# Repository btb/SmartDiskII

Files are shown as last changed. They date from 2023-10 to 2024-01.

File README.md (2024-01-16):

# SmartDiskII

The SmartDiskII is basically an Apple "Liron" disk controller with the IWM chip
replaced by the discrete components from the Disk II controller, which
the IWM was originally based on, and using firmware (i.e. SoftSP) which
has been appropriately modified to use those components instead of the IWM.

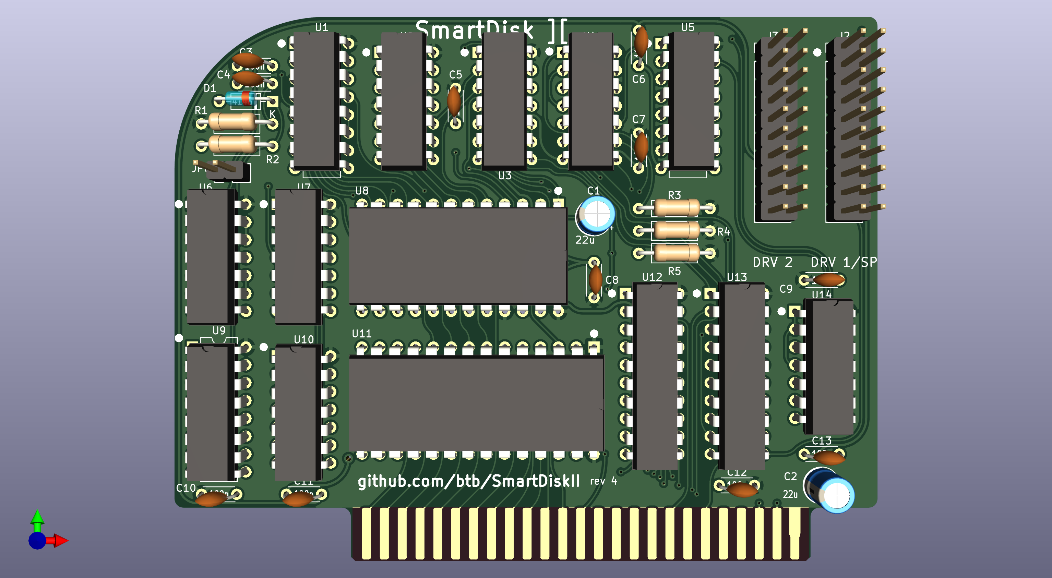
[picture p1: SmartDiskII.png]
image info


[Interactive BOM](https://btb.github.io/SmartDiskII/bom/SmartDiskII.html)

## SmartPort Operation

Because the SoftSP firmware (as of v6) is slot-dependent, a different copy is
required for each slot the card may be used in. The slot 1 version is in the 1xxx
region of the EPROM, slot 2 version is at 2xxx, etc.
A set of latches (U9) is used to automatically select the appropriate region
depending on which slot the SmartDiskII is placed in.

## Disk II Operation (experimental)

The card is designed to also work as a regular Disk II controller, though 
results can be inconsistent depending on the components used. Failures of 
this system can lead to corrupted floppy disks.

For this reason it is recommended to use true TTL ICs for all of the logic 
chips. In addition, for the chip at U5, Apple's original Disk II 
controller design called for a 9334 rather than a 74LS259. Indeed, using a 
9334 does appear to make the circuit more tolerant of these issues.  

5.25 Floppy operation works by having the Disk II boot rom in the 0xxx
region of the EPROM, and therefore active while U9 is held in
reset. Plugging a floppy drive into the DRV1 connector should automatically
activate the correct firmware because of the presence of +5V on pin 12, but
because some devices do not have that pin connected,
you can also close jumper JP8 to force the card into Disk II boot mode.

## Configuration

U8 is the standard [16-sector Disk II state machine data, P6](firmware/341-0128_P6A.bin), on a 2716-compatible EPROM.

U11 is a special combination of the Disk II boot ROM and the SoftSP firmware, [SmartDiskII.bin](firmware/SmartDiskII.bin).

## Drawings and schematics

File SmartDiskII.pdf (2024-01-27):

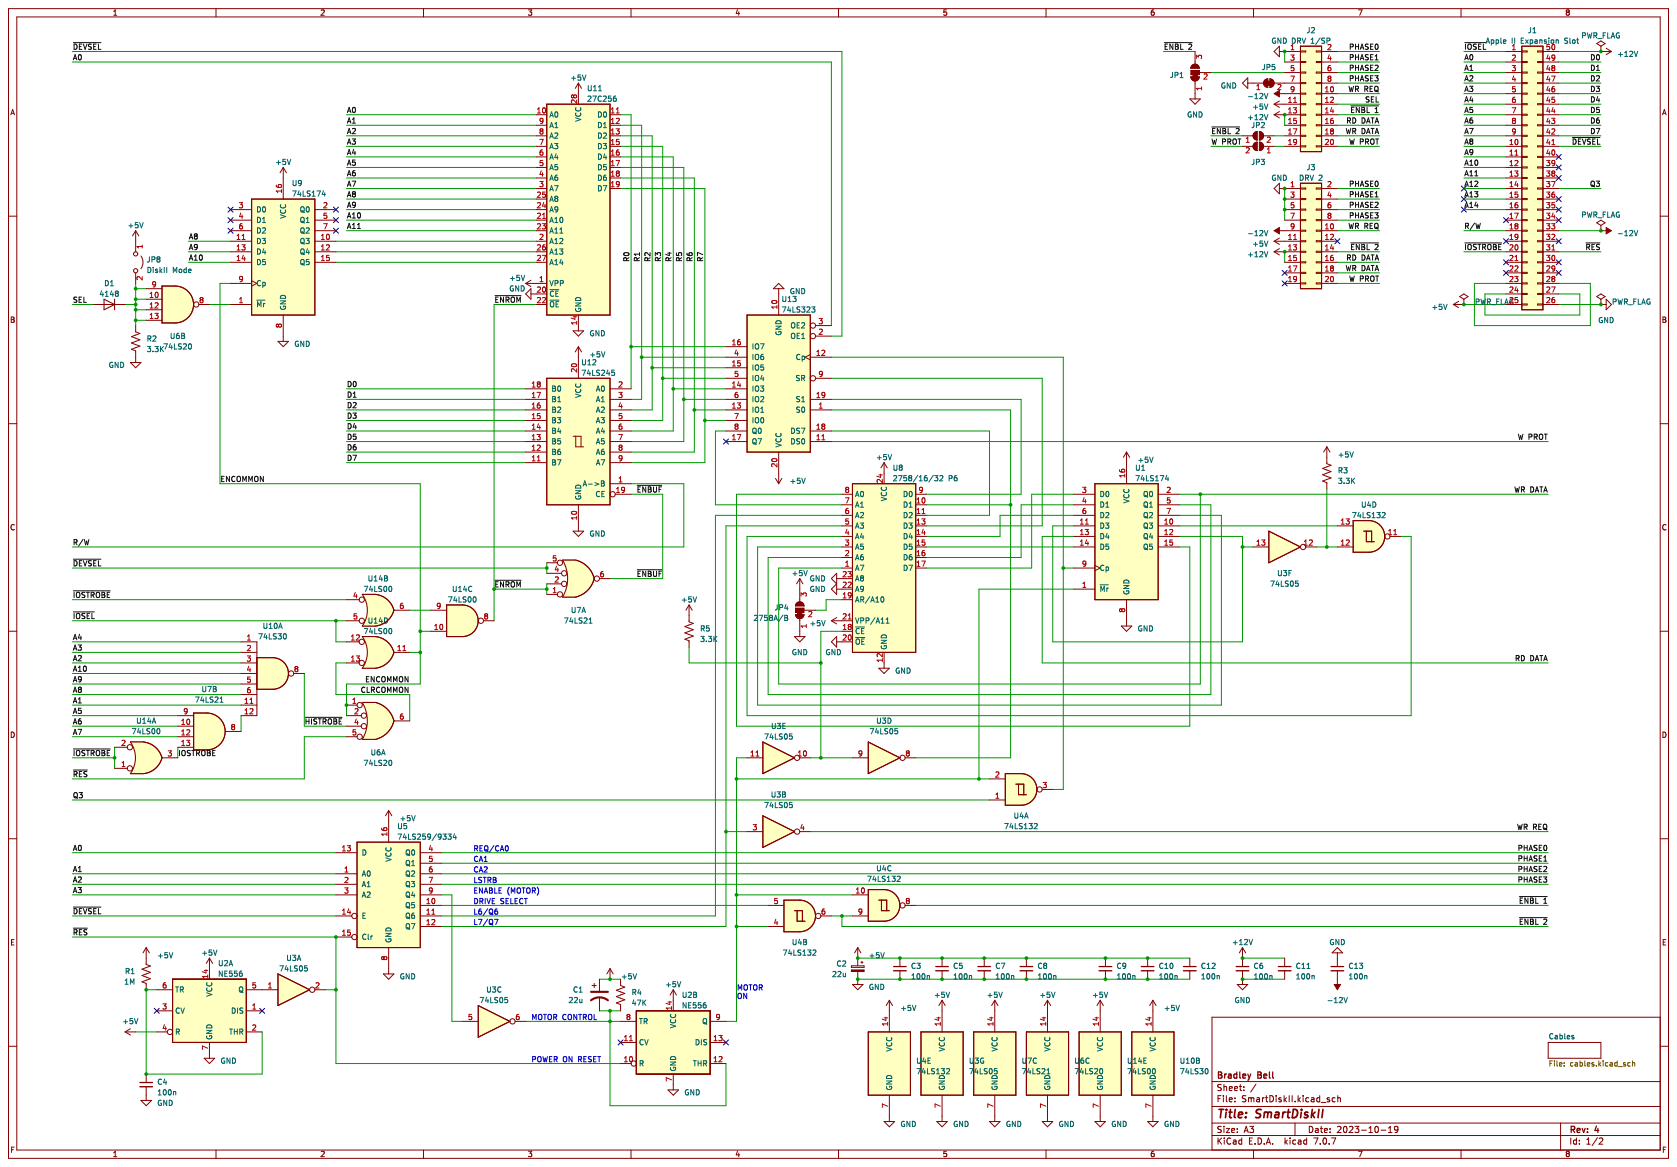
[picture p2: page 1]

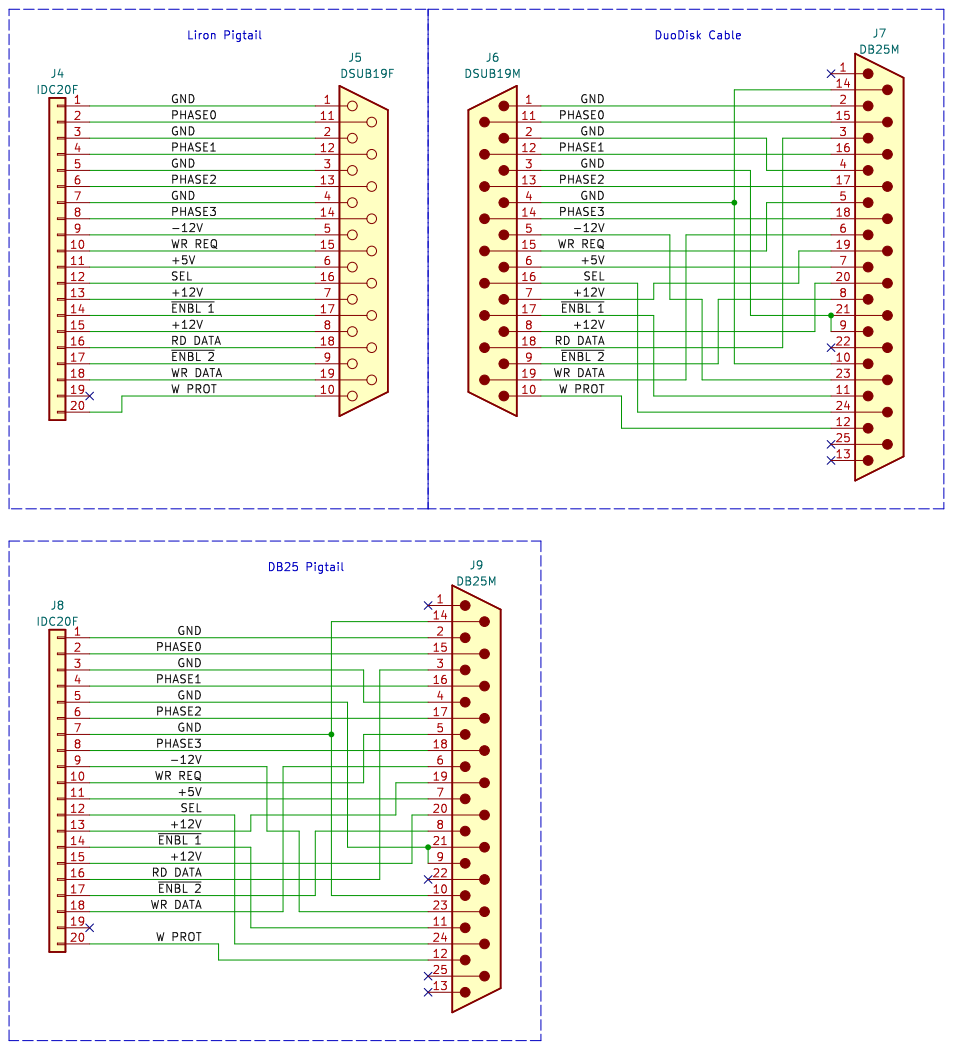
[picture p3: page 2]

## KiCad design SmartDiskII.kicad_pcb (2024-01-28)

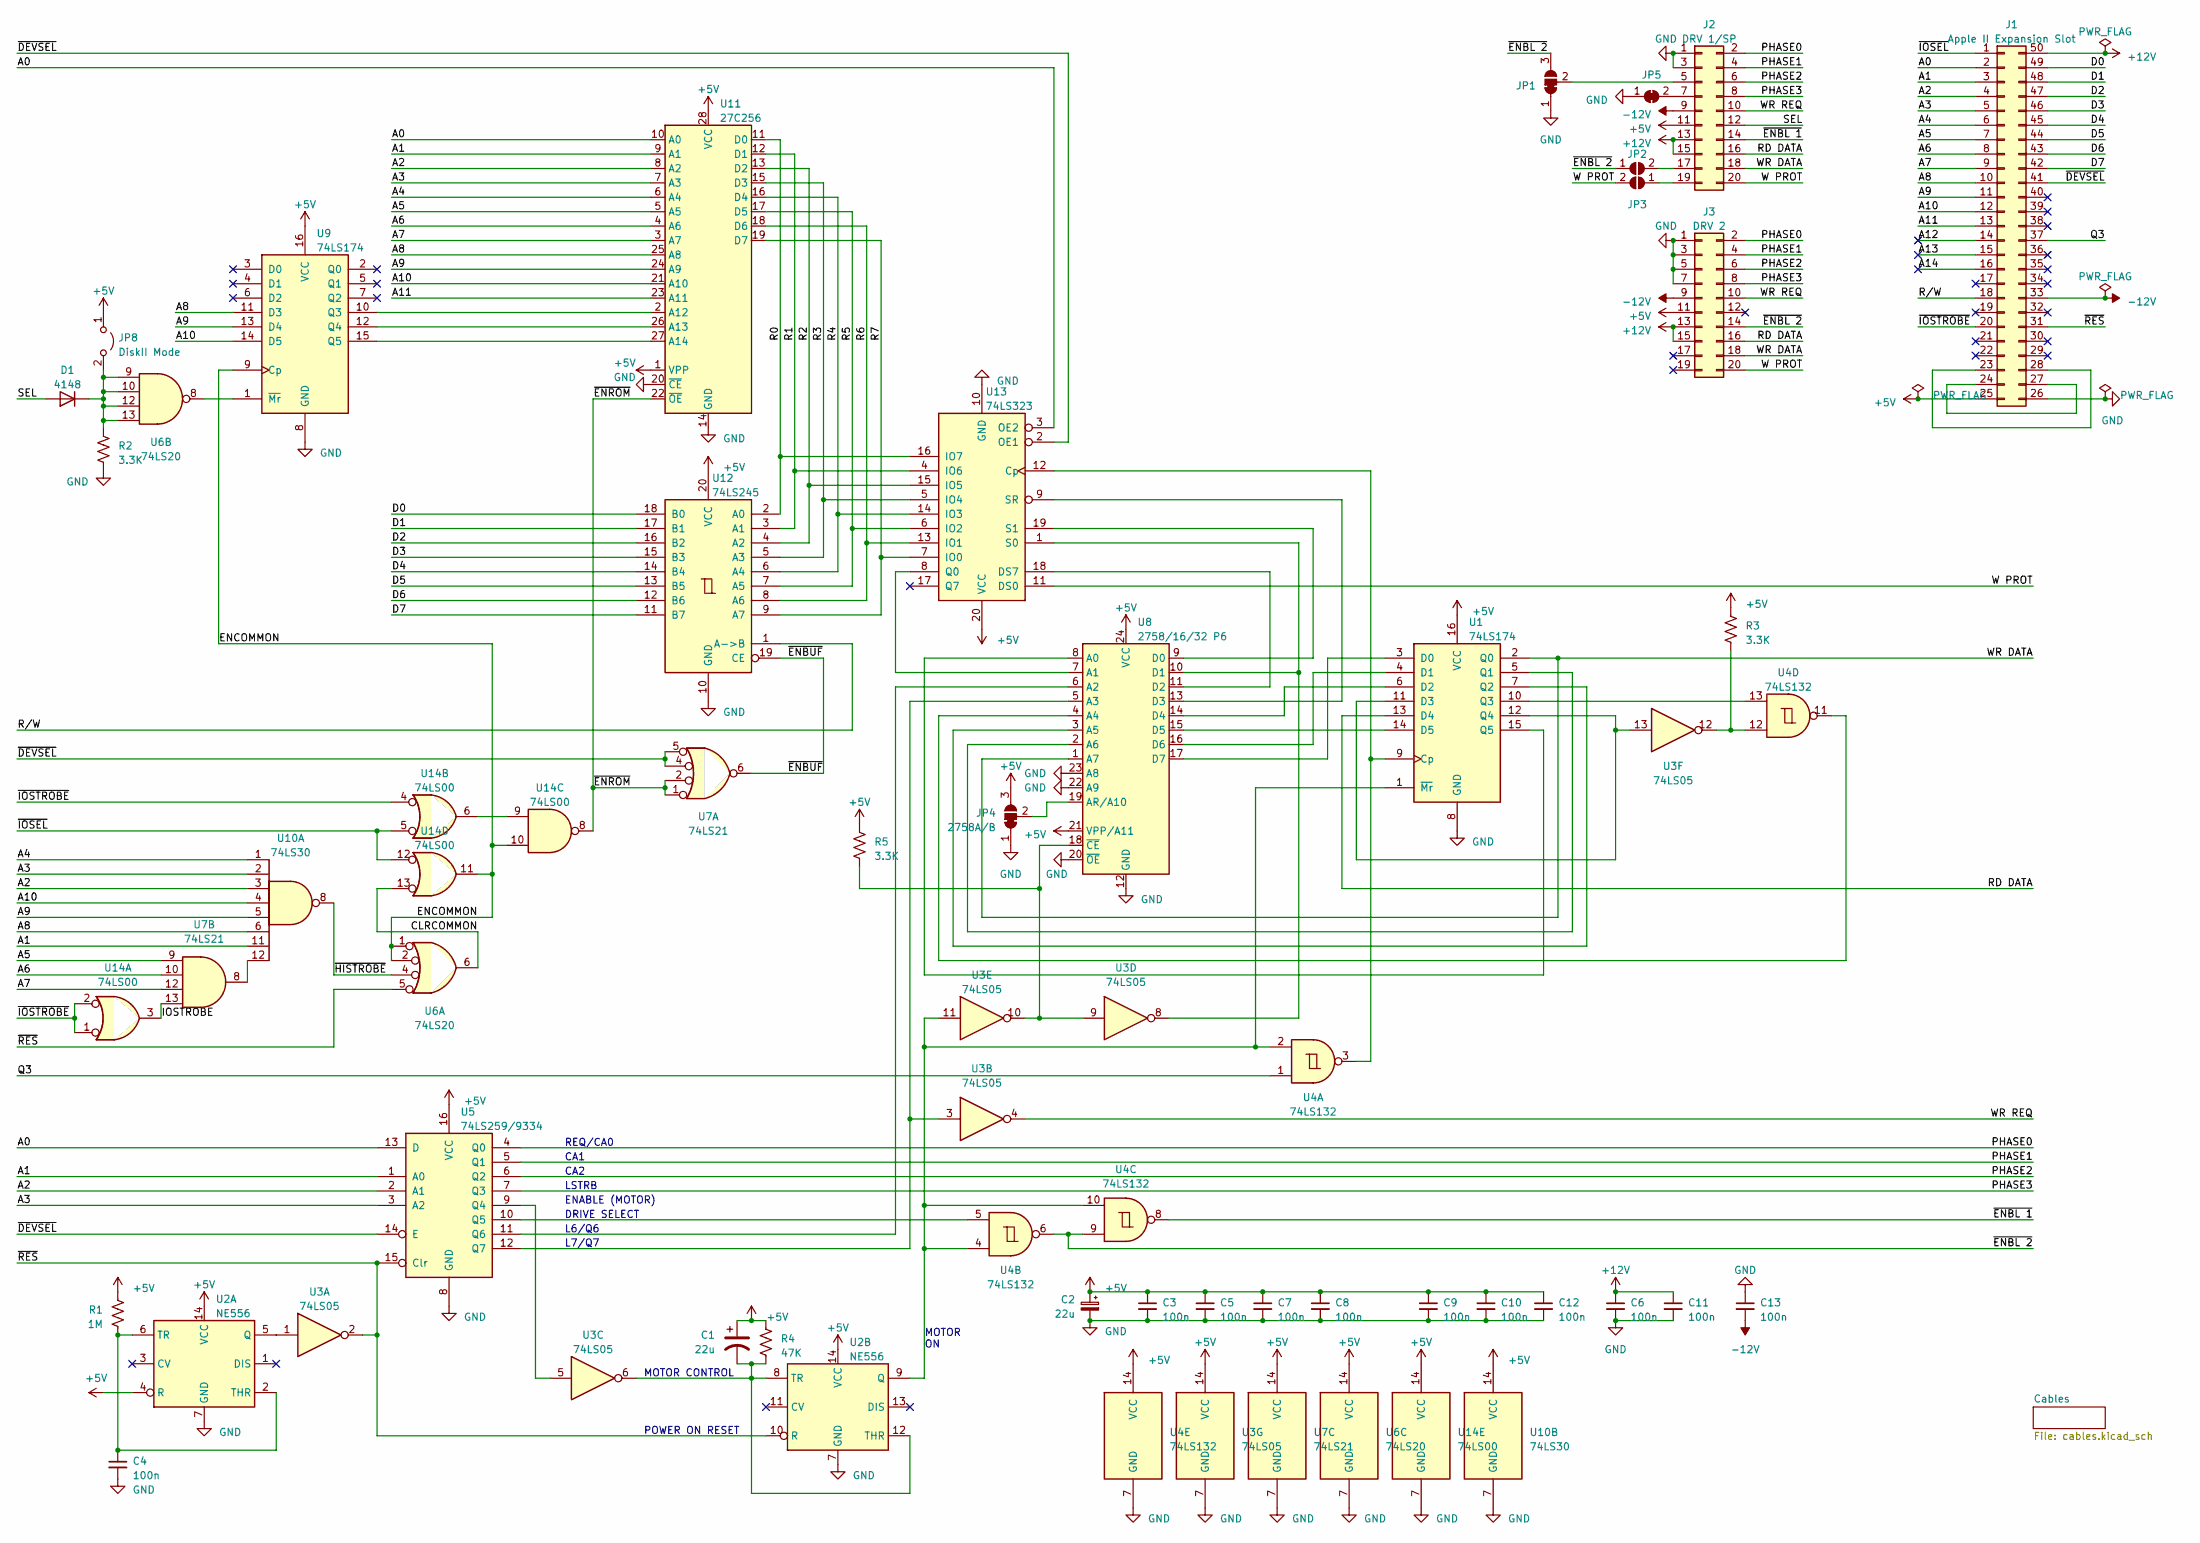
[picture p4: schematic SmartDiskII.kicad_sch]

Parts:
C1, C2: 22u; CP_Radial_D5.0mm_P2.50mm
C3, C4, C5, C6, C7, C8, C9, C10, C11, C12, C13: 100n; C_Disc_D4.3mm_W1.9mm_P5.00mm
D1: 4148; D_DO-35_SOD27_P7.62mm_Horizontal
J1: Apple II Expansion Slot; Apple II Expansion Edge Connector
J2: DRV 1/SP; PinHeader_2x10_P2.54mm_Vertical_Shrouded
J3: DRV 2; PinHeader_2x10_P2.54mm_Vertical_Shrouded
JP1: SolderJumper-3_P1.3mm_Bridged12_RoundedPad1.0x1.5mm_NumberL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
JP2, JP3: SolderJumper-2_P1.3mm_Open_RoundedPad1.0x1.5mm
JP4: 2758A/B; SolderJumper-3_P1.3mm_Bridged12_RoundedPad1.0x1.5mm_NumberL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
JP5: SolderJumper-2_P1.3mm_Bridged_RoundedPad1.0x1.5mm
JP8: DiskII Mode; PinHeader_1x02_P2.54mm_Vertical
R1: 1M; R_Axial_DIN0207_L6.3mm_D2.5mm_P10.16mm_Horizontal
R2, R3, R5: 3.3K; R_Axial_DIN0207_L6.3mm_D2.5mm_P10.16mm_Horizontal
R4: 47K; R_Axial_DIN0207_L6.3mm_D2.5mm_P10.16mm_Horizontal
U1, U9: 74LS174; DIP-16_W7.62mm
U2: NE556; DIP-14_W7.62mm
U3: 74LS05; DIP-14_W7.62mm
U4: 74LS132; DIP-14_W7.62mm
U5: 74LS259/9334; DIP-16_W7.62mm
U6: 74LS20; DIP-14_W7.62mm
U7: 74LS21; DIP-14_W7.62mm
U8: 2758/16/32 P6; DIP-24_W15.24mm
U10: 74LS30; DIP-14_W7.62mm
U11: 27C256; DIP-28_W15.24mm
U12: 74LS245; DIP-20_W7.62mm
U13: 74LS323; DIP-20_W7.62mm
U14: 74LS00; DIP-14_W7.62mm

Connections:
+5V: C1.1, C2.1, C3.1, C5.1, C7.1, C8.1, C9.1, C10.1, C12.1, J1.25, J2.11, J3.11, JP4.3 (B), JP8.1 (A), R1.1, R3.1, R4.2, R5.1, U1.16 (VCC), U2.4 (R), U2.14 (VCC), U3.14 (VCC), U4.14 (VCC), U5.16 (VCC), U6.14 (VCC), U7.14 (VCC), U8.21 (VPP/A11), U8.24 (VCC), U9.16 (VCC), U10.14 (VCC), U11.1 (VPP), U11.28 (VCC), U12.20 (VCC), U13.20 (VCC), U14.14 (VCC)
+12V: C6.1, C11.1, J1.50, J2.13, J2.15, J3.13, J3.15
-12V: C13.2, J1.33, J2.9, J3.9
/A0: J1.2, U5.13 (D), U11.10 (A0), U13.3 (OE2)
/A1: J1.3, U5.1 (A0), U10.11, U11.9 (A1)
/A2: J1.4, U5.2 (A1), U10.3, U11.8 (A2)
/A3: J1.5, U5.3 (A2), U10.2, U11.7 (A3)
/A4: J1.6, U10.1, U11.6 (A4)
/A5: J1.7, U7.9, U11.5 (A5)
/A6: J1.8, U7.10, U11.4 (A6)
/A7: J1.9, U7.12, U11.3 (A7)
/A8: J1.10, U9.11 (D3), U10.6, U11.25 (A8)
/A9: J1.11, U9.13 (D4), U10.5, U11.24 (A9)
/A10: J1.12, U9.14 (D5), U10.4, U11.21 (A10)
/A11: J1.13, U11.23 (A11)
/A12: J1.14
/A13: J1.15
/A14: J1.16
/CLRCOMMON: U6.6, U14.13
/D0: J1.49, U12.18 (B0)
/D1: J1.48, U12.17 (B1)
/D2: J1.47, U12.16 (B2)
/D3: J1.46, U12.15 (B3)
/D4: J1.45, U12.14 (B4)
/D5: J1.44, U12.13 (B5)
/D6: J1.43, U12.12 (B6)
/D7: J1.42, U12.11 (B7)
/ENCOMMON: U6.1, U6.2, U9.9 (Cp), U14.10, U14.11
/IOSTROBE: U7.13, U14.3
/PHASE0: J2.2, J3.2, U5.4 (Q0)
/PHASE1: J2.4, J3.4, U5.5 (Q1)
/PHASE2: J2.6, J3.6, U5.6 (Q2)
/PHASE3: J2.8, J3.8, U5.7 (Q3)
/Q3: J1.37, U4.1
/R0: U11.11 (D0), U12.2 (A0), U13.16 (IO7)
/R1: U11.12 (D1), U12.3 (A1), U13.4 (IO6)
/R2: U11.13 (D2), U12.4 (A2), U13.15 (IO5)
/R3: U11.15 (D3), U12.5 (A3), U13.5 (IO4)
/R4: U11.16 (D4), U12.6 (A4), U13.14 (IO3)
/R5: U11.17 (D5), U12.7 (A5), U13.6 (IO2)
/R6: U11.18 (D6), U12.8 (A6), U13.13 (IO1)
/R7: U11.19 (D7), U12.9 (A7), U13.7 (IO0)
/RD DATA: J2.16, J3.16, U1.13 (D4)
/R/W: J1.18, U12.1 (A->B)
/SEL: D1.2 (A), J2.12
/W PROT: J2.20, J3.20, JP3.2 (B), U13.11 (DS0)
/WR DATA: J2.18, J3.18, U1.2 (Q0), U8.1 (A7)
/WR REQ: J2.10, J3.10, U3.4
/~DEVSEL: J1.41, U5.14 (E), U7.4, U7.5, U13.2 (OE1)
/~ENBL 1: J2.14, U4.8
/~ENBL 2: J3.14, JP1.3 (B), JP2.1 (A), U4.6, U4.9
/~ENBUF: U7.6, U12.19 (CE)
/~ENROM: U7.1, U7.2, U11.22 (~OE), U14.8
/~HISTROBE: U6.4, U10.8
/~IOSEL: J1.1, U14.5, U14.12
/~IOSTROBE: J1.20, U14.1, U14.2, U14.4
/~RES: J1.31, U2.10 (R), U3.2, U5.15 (Clr), U6.5
GND: C2.2, C3.2, C4.2, C5.2, C6.2, C7.2, C8.2, C9.2, C10.2, C11.2, C12.2, C13.1, J1.26, J2.1, J2.3, J3.1, J3.3, J3.5, J3.7, JP1.1 (A), JP4.1 (A), JP5.1 (A), R2.2, U1.8 (GND), U2.7 (GND), U3.7 (GND), U4.7 (GND), U5.8 (GND), U6.7 (GND), U7.7 (GND), U8.12 (GND), U8.20 (~OE), U8.22 (A9), U8.23 (A8), U9.8 (GND), U10.7 (GND), U11.14 (GND), U11.20 (~CE), U12.10 (GND), U13.10 (GND), U14.7 (GND)
unnamed: D1.1 (K), JP8.2 (B), R2.1, U6.9, U6.10, U6.12, U6.13
unnamed: J1.23, J1.28
unnamed: J1.24, J1.27
unnamed: J2.5, JP1.2 (C)
unnamed: J2.7, JP5.2 (B)
unnamed: J2.17, JP2.2 (B)
unnamed: J2.19, JP3.1 (A)
unnamed: JP4.2 (C), U8.19 (AR/A10)
unnamed: R3.2, U3.12, U4.12
unnamed: U1.9 (Cp), U4.3, U13.12 (Cp)
unnamed: U1.3 (D0), U8.17 (D7)
unnamed: U1.4 (D1), U8.16 (D6)
unnamed: U1.6 (D2), U8.14 (D4)
unnamed: U1.11 (D3), U1.12 (Q4), U3.13
unnamed: U1.14 (D5), U8.15 (D5)
unnamed: U1.5 (Q1), U8.2 (A6)
unnamed: U1.7 (Q2), U8.3 (A5)
unnamed: U1.10 (Q3), U4.13
unnamed: U1.15 (Q5), U8.8 (A0)
unnamed: U1.1 (~Mr), U2.9 (Q), U3.11, U4.2, U4.4, U4.10
unnamed: U2.5 (Q), U3.1
unnamed: C4.1, R1.2, U2.2 (THR), U2.6 (TR)
unnamed: C1.2, R4.1, U2.8 (TR), U2.12 (THR), U3.6
unnamed: U3.5, U5.9 (Q4)
unnamed: U4.5, U5.10 (Q5)
unnamed: U5.11 (Q6), U8.6 (A2)
unnamed: U3.3, U5.12 (Q7), U8.5 (A3)
unnamed: U4.11, U8.4 (A4)
unnamed: R5.2, U3.9, U3.10, U8.18 (~CE)
unnamed: U6.8, U9.1 (~Mr)
unnamed: U7.8, U10.12
unnamed: U9.10 (Q3), U11.2 (A12)
unnamed: U9.12 (Q4), U11.26 (A13)
unnamed: U9.15 (Q5), U11.27 (A14)
unnamed: U8.11 (D2), U13.18 (DS7)
unnamed: U8.7 (A1), U13.8 (Q0)
unnamed: U3.8, U8.10 (D1), U13.1 (S0)
unnamed: U8.9 (D0), U13.19 (S1)
unnamed: U8.13 (D3), U13.9 (SR)
unnamed: U14.6, U14.9

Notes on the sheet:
MOTOR ON
CA2
REQ/CA0
POWER ON RESET
ENABLE (MOTOR)
L7/Q7
DRIVE SELECT
MOTOR CONTROL
L6/Q6
CA1
LSTRB

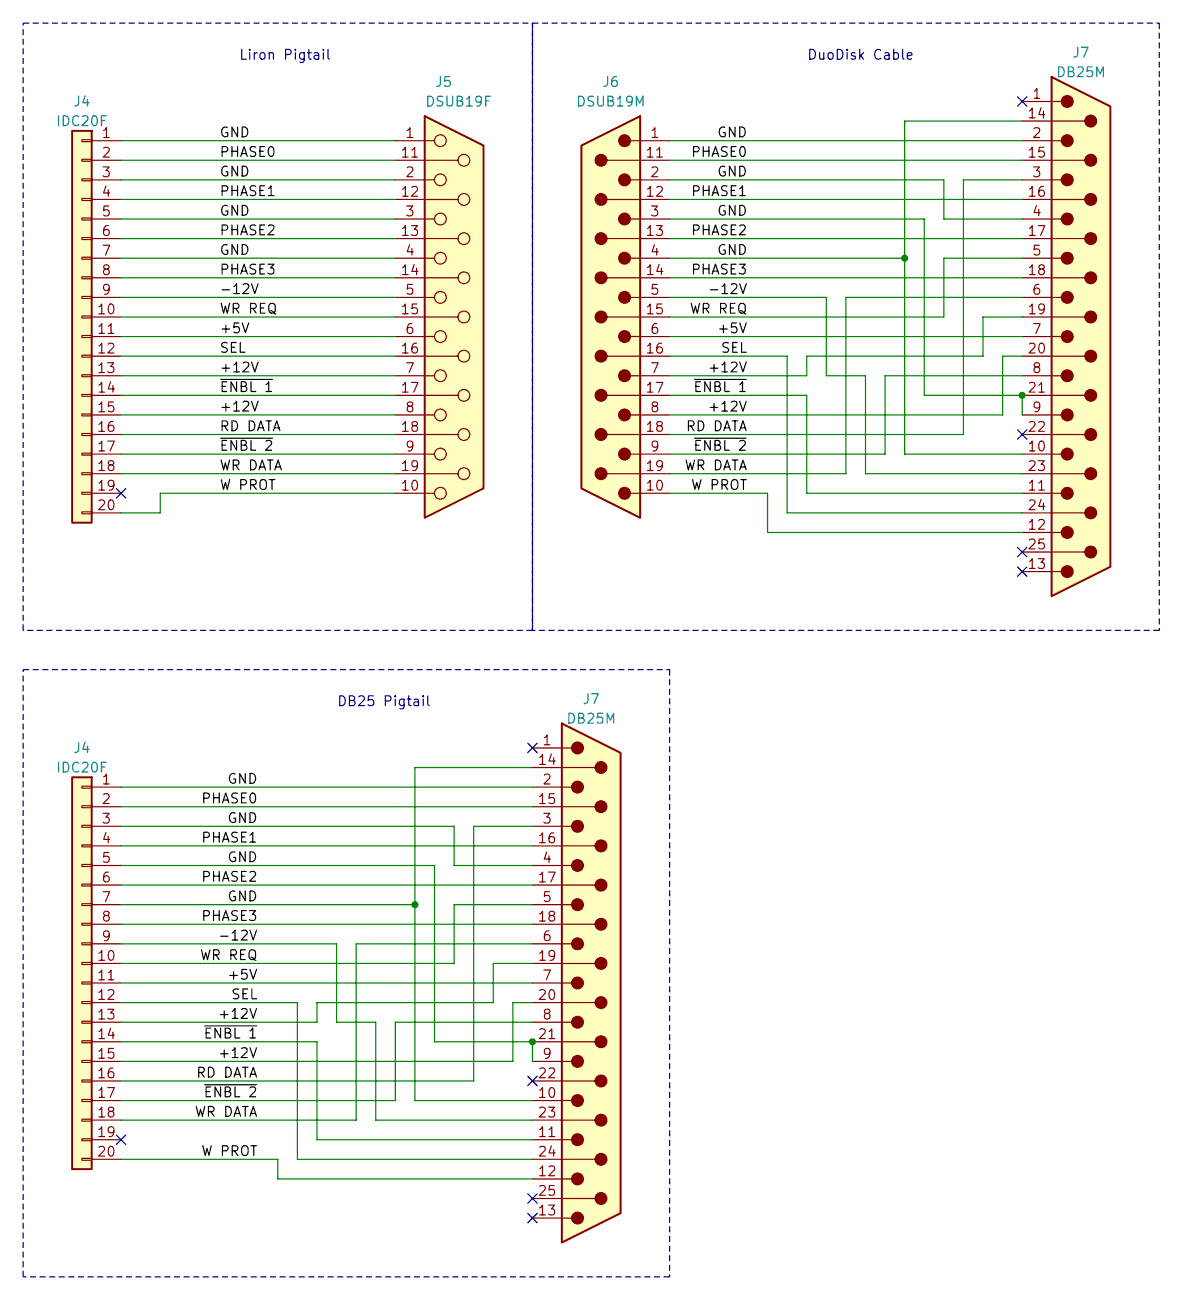
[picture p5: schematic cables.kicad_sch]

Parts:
J4: IDC20F
J5: DSUB19F
J6: DSUB19M
J7: DB25M

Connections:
unnamed: J4.1, J4.3, J4.5, J4.7, J5.1, J5.2, J5.3, J5.4, J6.1, J6.2, J6.3, J6.4, J7.2, J7.4, J7.9, J7.10, J7.14, J7.21
unnamed: J4.2, J5.11, J6.11, J7.15
unnamed: J4.4, J5.12, J6.12, J7.16
unnamed: J4.6, J5.13, J6.13, J7.17
unnamed: J4.8, J5.14, J6.14, J7.18
unnamed: J4.9, J5.5, J6.5, J7.23
unnamed: J4.10, J5.15, J6.15, J7.5
unnamed: J4.11, J5.6, J6.6, J7.7
unnamed: J4.12, J5.16, J6.16, J7.24
unnamed: J4.13, J4.15, J5.7, J5.8, J6.7, J6.8, J7.19, J7.20
unnamed: J4.14, J5.17, J6.17, J7.11
unnamed: J4.16, J5.18, J6.18, J7.3
unnamed: J4.17, J5.9, J6.9, J7.8
unnamed: J4.18, J5.19, J6.19, J7.6
unnamed: J4.20, J5.10, J6.10, J7.12

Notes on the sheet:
DuoDisk Cable
Liron Pigtail
DB25 Pigtail

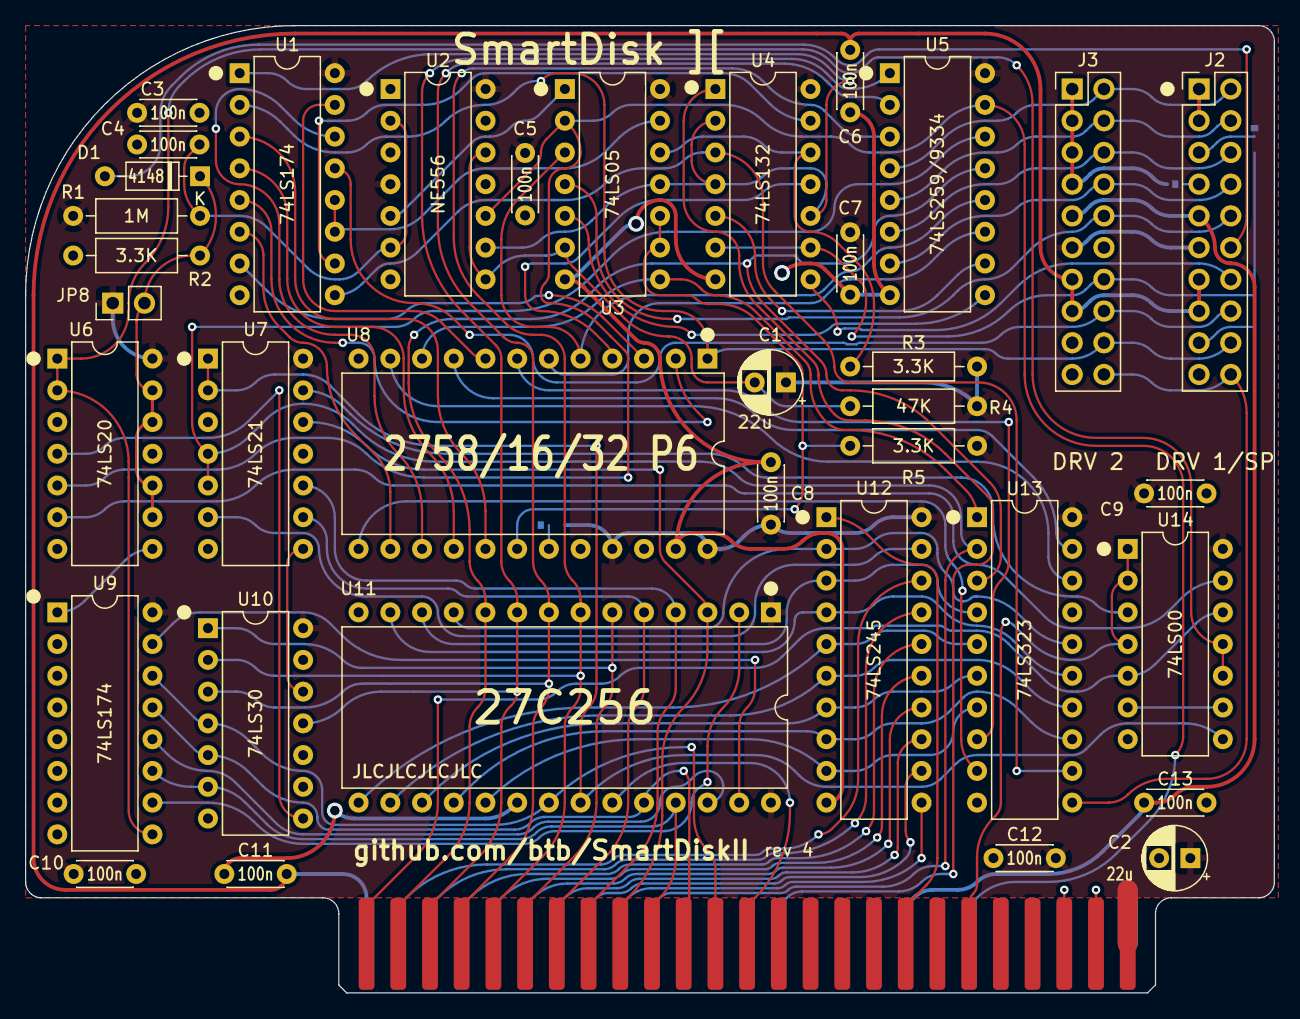
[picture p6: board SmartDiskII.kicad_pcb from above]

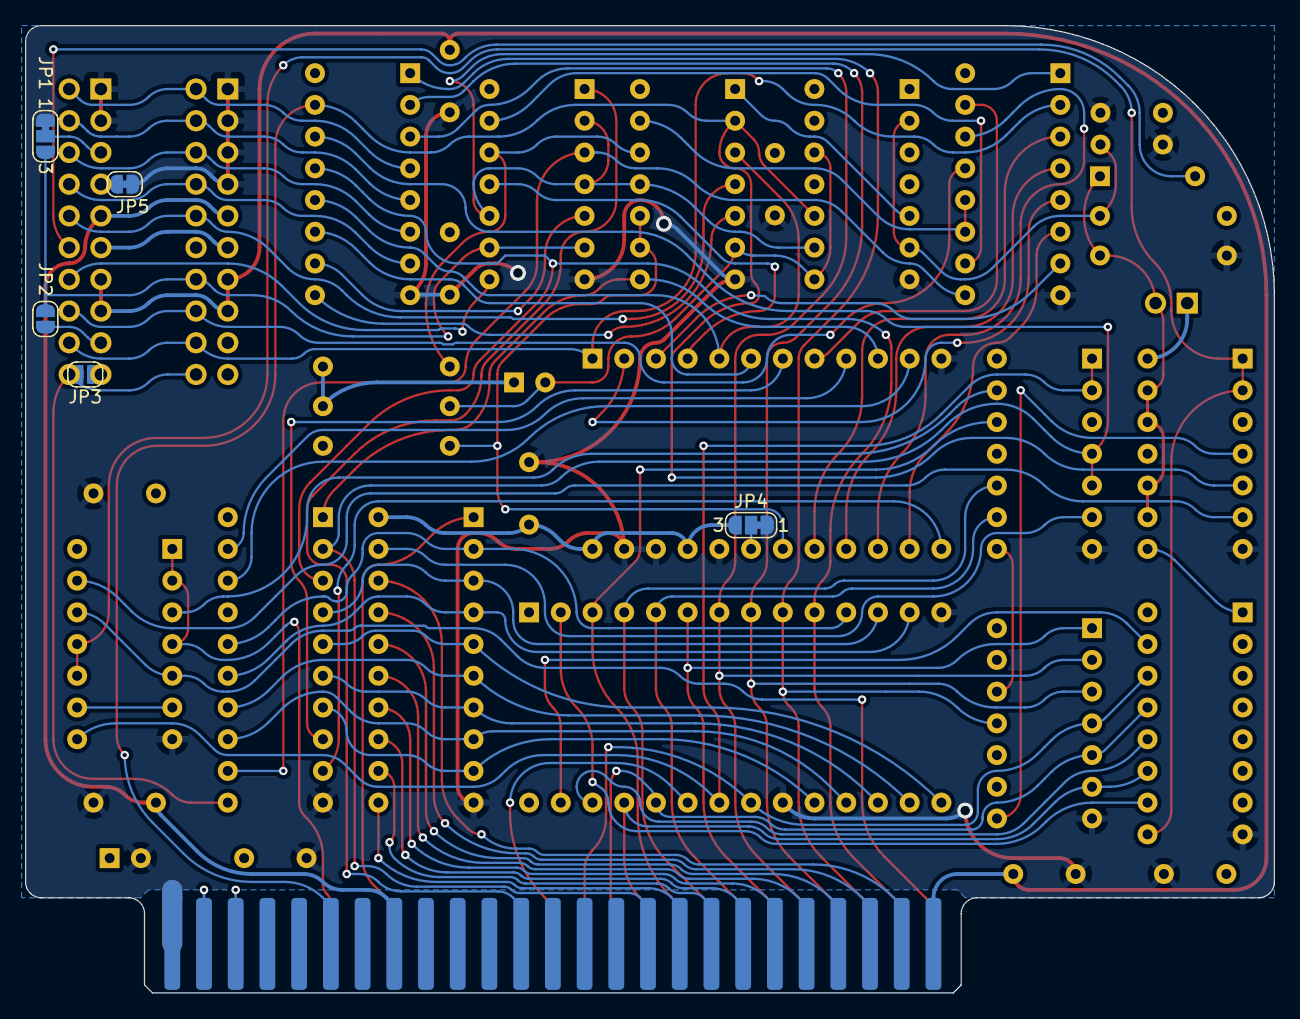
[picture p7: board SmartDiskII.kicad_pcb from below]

Board: 2 copper layers, 100.0 x 77.5 mm, 42 parts (5 on the bottom side), 95 nets.

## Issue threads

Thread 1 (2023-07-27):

Needs 7M

btb, 2023-07-27:
I've built this card up (rev0) and not surprisingly, it doesn't work (hangs on PR#5).

As I have a real IWM chip that I pulled from a Mac SE, I can remove all the chips from this board that make up the "Disk II" state machine, and wire up the IWM in their place, and it does the same thing. The one missing signal on this board compared to a Liron with IWM is the 7M clock. If I connect a wire from the 7M finger to the IWM, it works (as it should since this is now 100% a clone of the Liron card itself)

So, this circuit doesn't emulate a IWM enough to boot a smartport device, some change is needed to make use of 7M (rather than Q3?)
Or, the firmware can be customized to make it work without the 7M signal (this must be what the SoftSP firmware does)

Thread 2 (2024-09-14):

unable to get this to work with apple ii floppy drive?

AP2K94, 2024-09-14:
updated - Hi and thanks for this cool card, had a chance to build one on my holidays (after talking to a few people I tried an older 2732 eprom and it worked with j8 jumper on) with a real floppy drive, boots nice and no issues now so happy with that as can use my real floppy now.

I then borrowed a friends wdrive to test smartport, it works but strange issue occurring - it works with 32mb images in prodos but total replay.hdv wont boot when j8 in disk ii mode but strangely if we remove jumper and reboot it will boot the last image selected (even total replay works?) has anyone else had this issue or knows why this is occurring with total replay, which I think is non prodos based?
Again I tried J8 jumper in off position it powers on the wdrive but fails to boot images?

I suspect its an issue with the firmware at U11 but not sure?

I noticed a few solder pads on the back of the pcb near the idc20 headers is there a list for what these are/do? (ps I have not put solder on these/ left them as is)

Any idea what i can test or try next to get this to work :-/

Thanks again from uk

btb, 2024-10-13:
The solder pads would be if you were using some kind of custom cable - best to leave them alone.

J8 should only be in place when connecting to (some) actual 5.25" floppy drives, or a drive emulator in 5.25" mode. I believe the wDrive has such a mode but I haven't tested it.

"total replay.hdv" is definitely a prodos hard drive image, so you need J8 to be removed, and the card should be able to boot it. Just like with a real Liron, you may need to run "PR#5" to make it boot (replace "5" with whatever slot number you have the card in)

AP2K94, 2024-10-18:
have done some more testing with wdrive, basically with J8 off it wont boot the wdrive just goes to the prompt, typing PR#7 (card in slot 7) NO DEVICE IS CONNECTED is displayed, typing PR#7 again this time it will boot total replay and works....rebooting the IIe it will then automatically boot total replay, at every reboot...

with J8 jumper on, this time wdrive is booted , however selecting total replay from the menu , it will display softsp booting and crash, however if we immediately reboot the iie it will then boot total replay normally? (just like in the previous example)

It seems like the softsp code is not being assigned properly? It only seems to work correctly on a second reboot?

Interesting that with j8 enabled it works in both 5.25" fdd mode and (smartport mode only after a reboot)

Wondering if there is alternative firmware to try/test? / If there is anything you need me to test happy to help while I still have the borrowed wdrive :-)

thanks again

AP2K94, 2025-03-23:
all working now :-) all my devices boot , a friend helped change a few logic chips and its been rock solid stable! Not cheap to build but a great investment. Will look at adding a drive switch so I can change boot drive (1-2 /2-1) would be nice. Thanks again!

Closed 2025-03-23.

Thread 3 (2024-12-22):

Smartport Emulation issue

vibr77, 2024-12-22:
Hi Bradley,
I am working on a Apple II Hardware emulator based on STM32, https://github.com/vibr77/AppleIIDiskIIStm32F411
I have almost finished the DISKII emulation, and I have built a SmartDisk II card,

My emulator is working fine on IIc and IIGS with a proper SmartPort, but when I use the SmartDisk card it does not work.
I have plug my protocol analyser and I have strange WR_DATA.

the SmartDisk II is in slot 5, I have used the Smartdisk.bin firmware on GitHub. Do I need to do something special to make it work ?

on the Screen I have  I/O Error,
on my debug console I receive the Reset msg (phase 0x05) and then I have 2 cmd (0x0f, or 0x0a,, 0x0b) but the content of the message is empty

thanks for your help

Vincent

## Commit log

2023-09-24 add board files
    [SmartDiskII.kicad_pcb, SmartDiskII.kicad_sch]
2023-09-24 new revision
    only one drive connector, configurable with jumpers
    optionally use 2764 EPROM
    [SmartDiskII.kicad_pcb, SmartDiskII.kicad_sch]
2023-09-24 use liron pinout with jumpers for EN2
    [SmartDiskII.kicad_pcb, SmartDiskII.kicad_sch]
2023-09-24 update kicad files
    [SmartDiskII.kicad_pcb, SmartDiskII.kicad_sch]
2023-10-03 add page for cables
    [SmartDiskII.kicad_sch, cables.kicad_sch]
2023-10-09 All slot auto-switching rom
    [SmartDiskII.kicad_pcb, SmartDiskII.kicad_sch]
2023-10-11 fix jumper, tweaks
    [SmartDiskII.kicad_pcb, SmartDiskII.kicad_sch]
2023-10-12 Working circuit for multi-rom
    [SmartDiskII.kicad_pcb, SmartDiskII.kicad_sch]
2023-10-12 invert /SEL for auto detect of 5.25 floppy
    [SmartDiskII.kicad_pcb, SmartDiskII.kicad_sch]
2023-10-12 readd second floppy connector
    reference number changes
    [SmartDiskII.kicad_pcb, SmartDiskII.kicad_sch, cables.kicad_sch]
2023-10-20 Protect pin 12 with Diode
    [SmartDiskII.kicad_pcb, SmartDiskII.kicad_sch, cables.kicad_sch]
2023-10-29 use 3.3k instead of 3k. gnd jumper for drv pin 7
    [SmartDiskII.kicad_pcb, SmartDiskII.kicad_sch]
2023-10-29 remove old gerbers
2024-01-11 ground drive pin 7 by default
    [SmartDiskII.kicad_pcb, SmartDiskII.kicad_sch]
2024-01-28 tweak back silkscreens
    [SmartDiskII.kicad_pcb]
2024-01-28 rev4 final gerbers
